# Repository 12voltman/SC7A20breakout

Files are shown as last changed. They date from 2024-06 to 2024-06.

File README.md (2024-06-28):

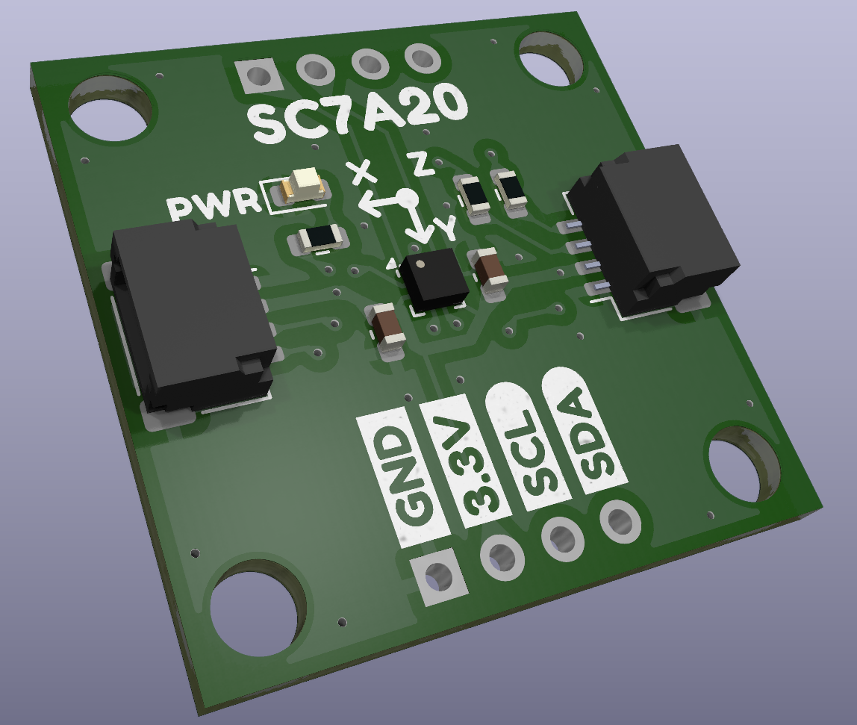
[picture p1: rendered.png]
Photorealistic render of square circuit board with various components mounted to it

# SC7A20breakout
Breakout for the SC7A20 low-cost 3-axis accelerometer  
## Features
- 12-bit range
- ±2G, ±4G, ±8G, ±16G selectable range
- 1-400Hz poll rate
- 1.7-3.6V operating voltage
- I<sup>2</sup>C/SPI/3-Wire SPI selectable interface
- 2 independent interrupts
- On-board 10k I<sup>2</sup>C pullups (cut jumper to disable)
- On-board power LED (cut jumper to disable)  
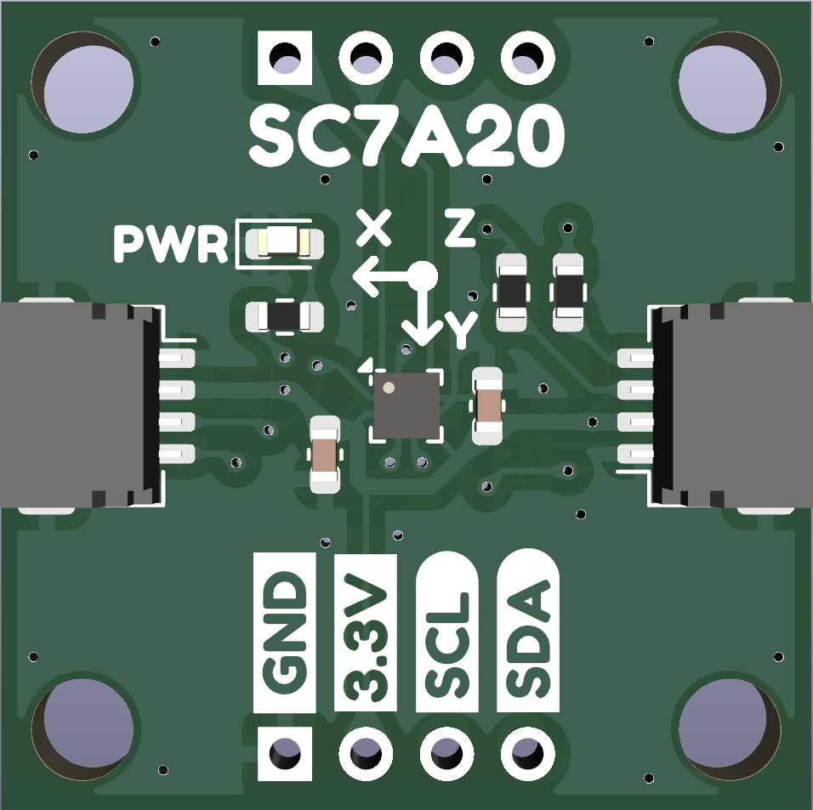
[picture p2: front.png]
Front flat view of PCB with components and silkscreen
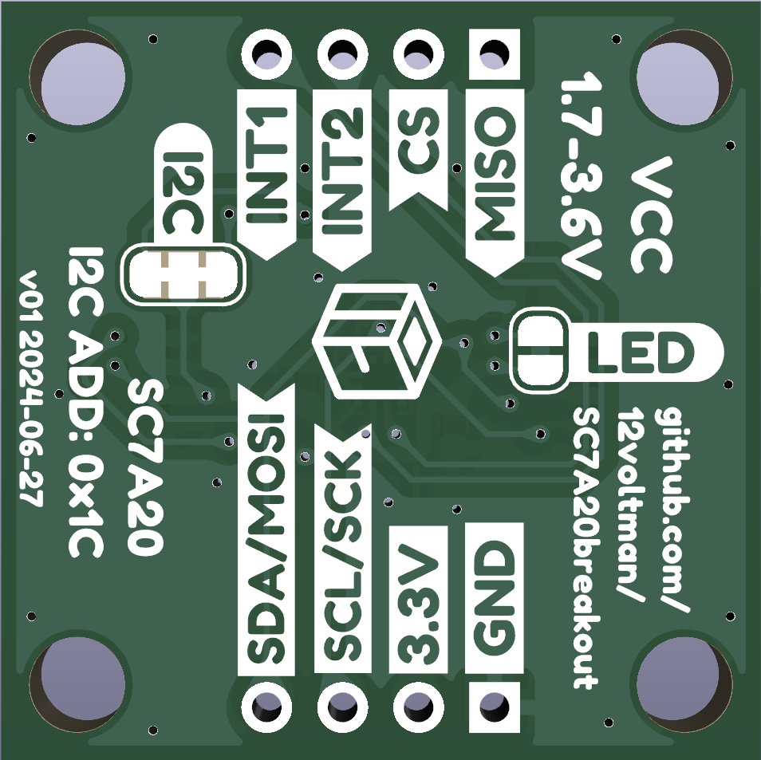
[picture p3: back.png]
Back flat view of PCB with cut jumpers and pin labels


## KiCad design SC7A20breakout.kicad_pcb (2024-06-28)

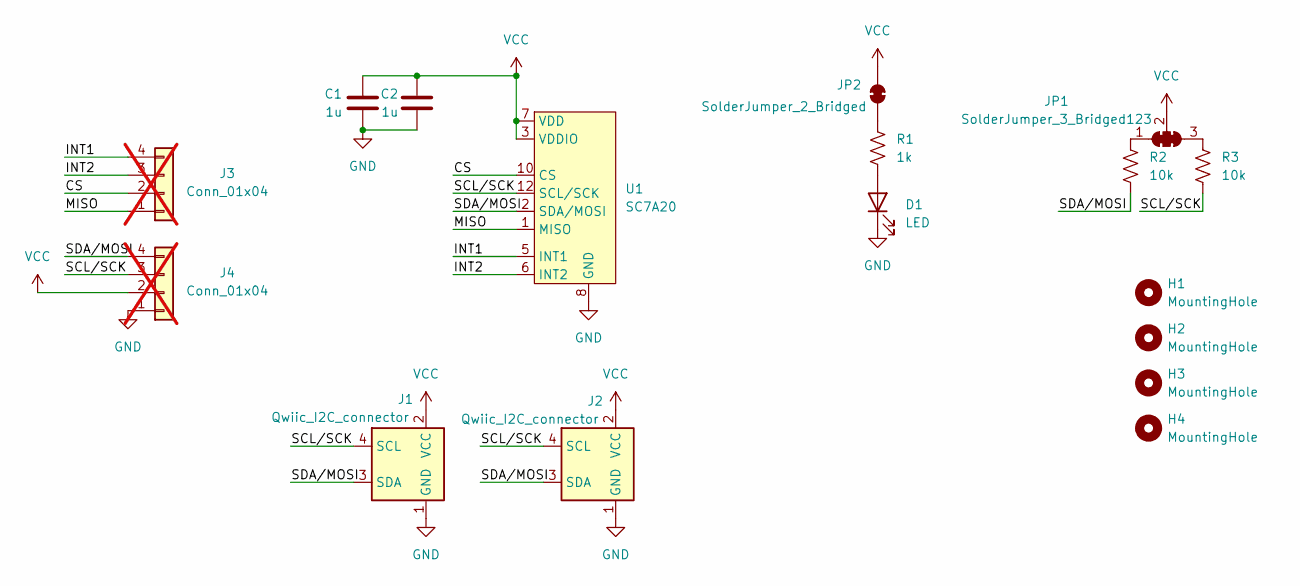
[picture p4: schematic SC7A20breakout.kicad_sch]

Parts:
C1, C2: 1u; C_0603_1608Metric; LCSC C15849
D1: LED; LED_0603_1608Metric; LCSC C2286
H1, H2, H3, H4: MountingHole; MountingHole_3.2mm_M3
J1, J2: Qwiic_I2C_connector; JST_SH_SM04B-SRSS-TB_1x04-1MP_P1.00mm_Horizontal; LCSC C7430446
J3, J4: Conn_01x04; PinHeader_1x04_P2.54mm_Vertical; not fitted
JP1: SolderJumper_3_Bridged123; SolderJumper-3_P1.3mm_Bridged123_RoundedPad1.0x1.5mm
JP2: SolderJumper_2_Bridged; SolderJumper-2_P1.3mm_Bridged_RoundedPad1.0x1.5mm
R1: 1k; R_0603_1608Metric; LCSC C21190
R2, R3: 10k; R_0603_1608Metric; LCSC C25804
U1: SC7A20; Kionix_LGA-12_2x2mm_P0.5mm_LayoutBorder2x4y; LCSC C5126709

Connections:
/CS: J3.2, U1.10 (CS)
/INT1: J3.4, U1.5 (INT1)
/INT2: J3.3, U1.6 (INT2)
/MISO: J3.1, U1.1 (MISO)
/SCL/SCK: J1.4 (SCL), J2.4 (SCL), J4.3, R3.2, U1.12 (SCL/SCK)
/SDA/MOSI: J1.3 (SDA), J2.3 (SDA), J4.4, R2.2, U1.2 (SDA/MOSI)
GND: C1.2, C2.2, D1.1 (K), J1.1 (GND), J1.MP (VSS), J2.1 (GND), J2.MP (VSS), J4.1, U1.8 (GND), U1.9 (GND)
unnamed: D1.2 (A), R1.2
unnamed: JP1.1 (A), R2.1
unnamed: JP1.3 (B), R3.1
unnamed: JP2.1 (A), R1.1
VCC: C1.1, C2.1, J1.2 (VCC), J2.2 (VCC), J4.2, JP1.2 (C), JP2.2 (B), U1.3 (VDDIO), U1.7 (VDD)

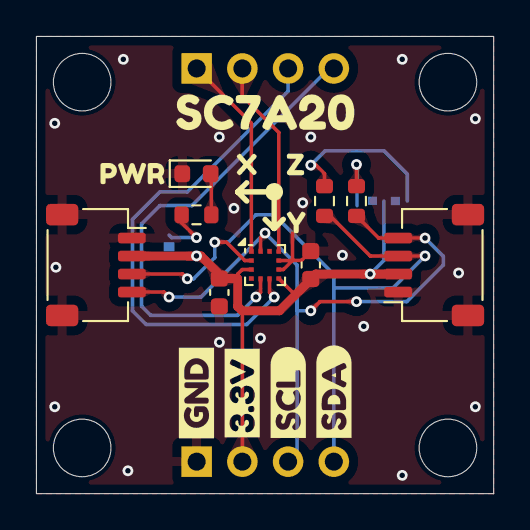
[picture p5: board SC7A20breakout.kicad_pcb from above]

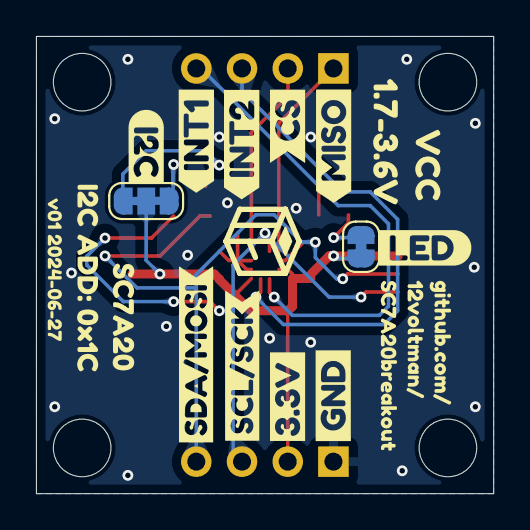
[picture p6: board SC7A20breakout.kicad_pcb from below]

Board: 2 copper layers, 25.4 x 25.4 mm, 40 parts (16 on the bottom side), 12 nets.

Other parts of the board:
kibuzzard-667CFAB6, kibuzzard-667CFAB6#2: G***; kibuzzard-667CFAB6
kibuzzard-667CFB53, kibuzzard-667CFB53#2: G***; kibuzzard-667CFB53
kibuzzard-667CFB75: G***; kibuzzard-667CFB75
kibuzzard-667CFBC3: G***; kibuzzard-667CFBC3
kibuzzard-667CFC6D: G***; kibuzzard-667CFC6D
kibuzzard-667CFC83: G***; kibuzzard-667CFC83
kibuzzard-667CFD0E: G***; kibuzzard-667CFD0E
kibuzzard-667CFD1C: G***; kibuzzard-667CFD1C
kibuzzard-667CFD41: G***; kibuzzard-667CFD41
kibuzzard-667CFD49: G***; kibuzzard-667CFD49
kibuzzard-667CFEC2: G***; kibuzzard-667CFEC2
kibuzzard-667D04C9: G***; kibuzzard-667D04C9
kibuzzard-667D053C: G***; kibuzzard-667D053C
kibuzzard-667D0532: G***; kibuzzard-667D0532
kibuzzard-667D0544: G***; kibuzzard-667D0544
kibuzzard-667DD6C5: G***; kibuzzard-667DD6C5
kibuzzard-667DDCB5: G***; kibuzzard-667DDCB5
kibuzzard-667DE64B: G***; kibuzzard-667DE64B
kibuzzard-667DE68B: G***; kibuzzard-667DE68B
kibuzzard-667DFE26: G***; kibuzzard-667DFE26
kibuzzard-667DFE33: G***; kibuzzard-667DFE33

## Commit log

2024-06-27 Preliminary revision PCB
    [SC7A20breakout.kicad_pcb, SC7A20breakout.kicad_sch]
2024-06-28 Correct hole spacing and labeling
    [SC7A20breakout.kicad_pcb, SC7A20breakout.kicad_sch]
2024-06-28 Switched to JLCPCB basic assembly parts
    [SC7A20breakout.kicad_pcb, SC7A20breakout.kicad_sch]
